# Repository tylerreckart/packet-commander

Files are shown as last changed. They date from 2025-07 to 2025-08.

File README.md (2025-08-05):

# Packet Commander
Complete 8-button WiFi IoT controller with hardware designs, firmware, and desktop configurator. Advanced configuration management, power optimization, and multi-protocol capabilities.

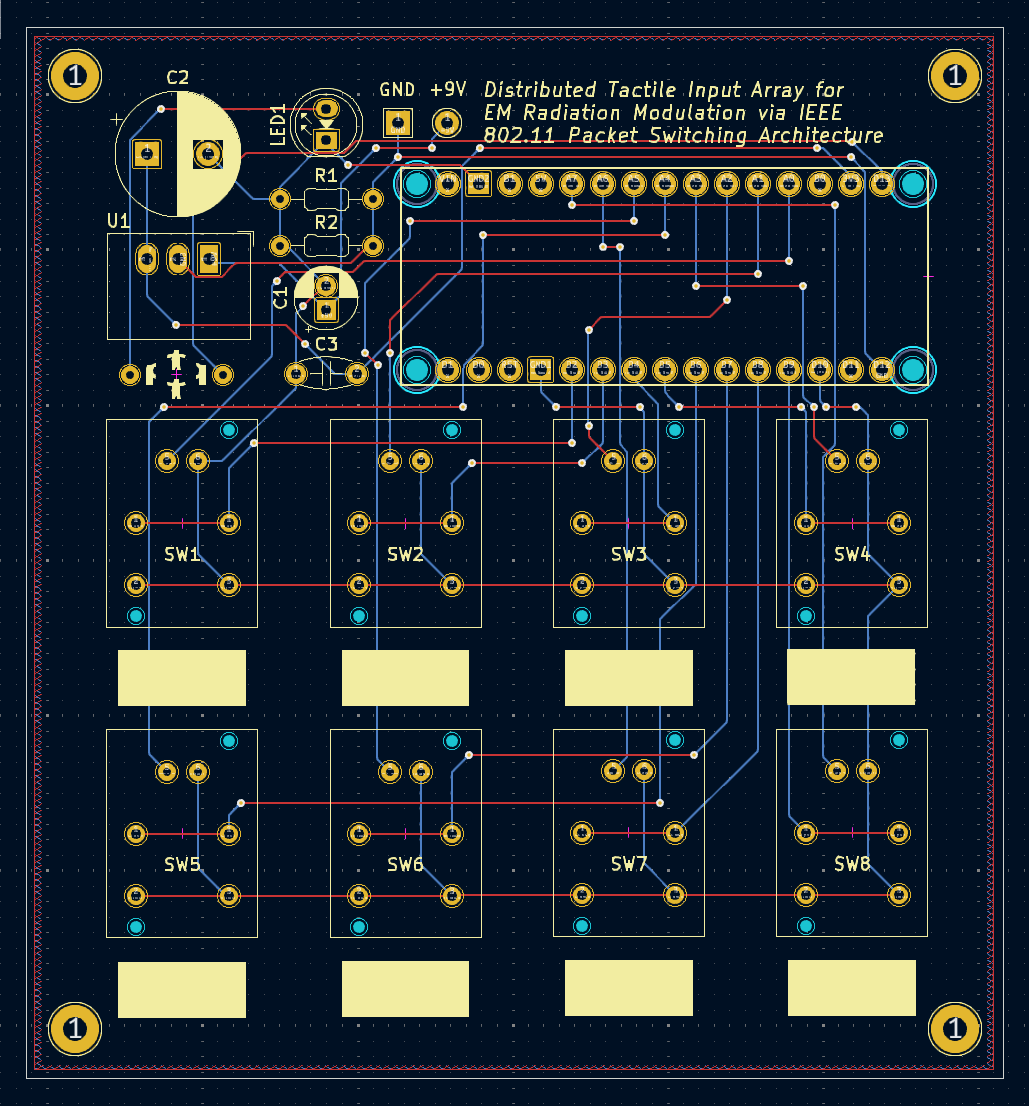
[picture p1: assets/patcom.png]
PATCOM


## Overview

Packet Commander is a complete IoT development platform featuring 8 programmable buttons with LED feedback, comprehensive WiFi connectivity, and intelligent power management. Includes hardware schematics, ESP32 firmware, and cross-platform Electron configurator for smart home automation, network testing, and custom IoT applications.

### Key Features
- **8 Programmable Buttons**: Directly supports HTTP and Webhook actions.
- **Smart Power Management**: Includes battery monitoring and optimized CPU frequency for power efficiency.
- **Desktop App**: Full-featured Electron configurator with device management.
- **Persistent Storage**: Configuration saved to flash memory on the device.
- **Multi-Protocol Support**: Firmware directly supports HTTP/HTTPS and Webhook.
- **Network Discovery**: Automatic device detection and configuration synchronization via the desktop application.

### Hardware Specs
- **MCU**: Arduino Nano ESP32 (Dual-core, 240MHz).
- **Inputs**: 8× illuminated tactile buttons (PB86).
- **Power**: 9V battery → 3.3V regulated (6-8 hour runtime).
- **Network**: 2.4GHz WiFi 802.11b/g/n.
- **Current**: 80-240mA.
- **Storage**: 4MB Flash, EEPROM for configuration.
- **Battery Monitor**: Real-time voltage sensing with low-battery alerts.

## Developer Quick Start

### For Configurator Development
```bash
# Install dependencies and run configurator
npm install
npm run build
npm run dev
```

### For Hardware Development
- Flash `firmware/patcom.cpp` to Arduino Nano ESP32
- Use configurator to connect and test device
- See [Circuit Assembly](#circuit-assembly) for complete build guide

### Prerequisites
- Node.js 18+ (for configurator)
- Arduino IDE 2.0+ (for firmware)
- KiCad (for hardware modifications)

## Quick Start

### 1. Hardware Setup
- Flash the firmware to your Arduino Nano ESP32.
- Connect 9V battery to power input.
- Power LED will indicate system status.

### 2. First Boot Configuration
1. Power on device - it will create "PATCOM-Config" WiFi hotspot.
2. Connect to hotspot (password: `patcom123`).
3. Open browser to `192.168.4.1`.
4. Configure your WiFi network and device settings.
5. Device will restart and connect to your network.

### 3. Desktop Configuration App

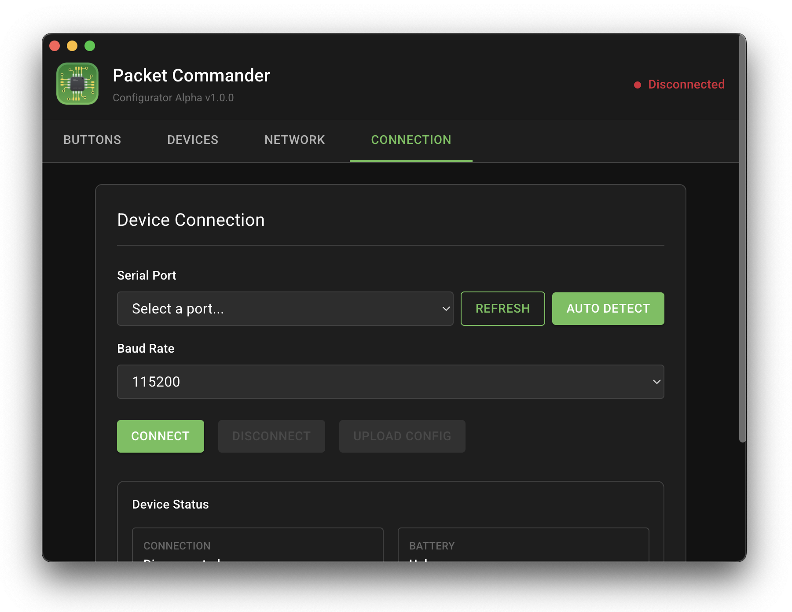
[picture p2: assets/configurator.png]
PATCOM Configurator


#### Development Commands
```bash
# Install dependencies
npm install

# Build all TypeScript
npm run build

# Run in development mode (with debug output)
npm run dev

# Run in production mode
npm start

# Build for distribution
npm run dist

# Type checking and linting
npm run type-check
npm run lint
```

#### Configurator Features
- **Device Auto-Detection**: USB serial and network discovery
- **Real-time Configuration**: Live button testing and LED control
- **Bulk Operations**: Configure multiple devices simultaneously
- **Configuration Backup**: Save/load device configurations as JSON
- **Debug Console**: Monitor device communication and troubleshoot issues

### 4. Device Discovery & Configuration
- Click "Discover Devices" to find controllers on your network
- Configure button actions: HTTP requests, webhooks.
- Upload configuration to device
- Test buttons and monitor activity

## Firmware Installation

### Arduino IDE Setup
- Download [Arduino IDE 2.0+](https://www.arduino.cc/en/software)
- Add ESP32 board URL in Preferences:
  ```
  https://espressif.github.io/arduino-esp32/package_esp32_index.json
  ```
- Install "Arduino ESP32 Boards" via Board Manager
- Install required libraries: ArduinoJson, AsyncUDP, ESPmDNS

### Firmware Upload
- Connect Arduino via USB-C
- Select: **Tools → Board → Arduino Nano ESP32**
- Select your port
- Open `firmware/patcom.cpp`
- Click Upload

## Configuration Management

### Button Action Types
- **HTTP/HTTPS**: Send GET/POST/PUT requests with custom headers and body
- **Webhook**: Secure webhook calls with device context and secrets
- **None**: Disable button (LED-only feedback)

### Device Settings
- **Network**: WiFi credentials, static IP configuration
- **Discovery**: Device name, auto-discovery, config sync settings
- **API Keys**: Secure storage for service credentials

### Configuration Storage
- Settings persisted to ESP32 flash memory
- Automatic backup during low battery
- Configuration hash verification
- Remote sync with desktop app

## Development & Debugging

### Device Communication
The configurator communicates with devices via:
- **USB Serial**: Direct connection for development (115200 baud)
- **Network Discovery**: UDP broadcast for deployed devices
- **HTTP API**: RESTful configuration on device port 80

### Debugging Tips
- Enable debug mode: `npm run dev` shows detailed console output
- Serial monitor: Built-in serial console for direct device communication
- Network scanner: "Discover Devices" shows all responsive controllers
- Configuration validation: Real-time validation with error highlighting

### File Structure
```
src/
├── main.ts              # Electron main process
├── preload.ts           # Secure IPC bridge  
├── renderer/            # UI components
├── services/            # Device communication
└── types/               # TypeScript definitions

firmware/
└── patcom.cpp           # ESP32 firmware

hardware/
└── *.kicad_*           # PCB design files
```

## Serial Commands (115200 baud)
- `STATUS` - Device information and battery status
- `CONFIG` - Display current configuration as JSON
- `SET_CONFIG:<json>` - Upload new configuration
- `TEST:<n>` - Test button n (0-7)
- `WIFI` - WiFi connection status
- `BATTERY` - Current battery voltage
- `HELP` - List all available commands

## Pin Connections

| Function | Pin | | Function | Pin |
|---|-----|-|---|-----|
| Button 0-7 | D2-D9 | | LED 0-7 | A0-A7 |
| Battery Monitor | A8 | | Status LED | D13 |
| Power In | 3V3 | | Ground | GND |
| USB Serial | USB-C | | Programming | BOOT + RESET |

## Circuit Assembly

### Parts List
- Packet Commander PCB
- Arduino Nano ESP32
- 8× PB86 switches
- RECOM R-78E3.3-1.0 regulator
- Capacitors: 100µF, 470µF, 10µF
- Resistors: 100kΩ, 33kΩ, 1kΩ
- 9V battery connector
- Terminal blocks

### Wiring
1. Battery → Regulator → Arduino 3V3 pin
2. Each button: terminal → Arduino pin, LED+ → analog pin
3. All grounds connected together
4. Battery monitor: voltage divider to D12

## Example Use Cases

### Smart Home Control
```json
{
  "action": "http",
  "config": {
    "url": "http://homeassistant.local:8123/api/services/light/toggle",
    "method": "POST",
    "headers": {"Authorization": "Bearer YOUR_TOKEN"},
    "body": "{\"entity_id\": \"light.living_room\"}"
  }
}
```

### Custom Webhook
```json
{
  "action": "webhook",
  "config": {
    "url": "https://api.example.com/webhook",
    "secret": "your-webhook-secret"
  }
}
```

## Troubleshooting

### Hardware Issues
| Issue | Solution |
|---|---|
| Upload fails | Hold RESET button during upload. Short GPIO0 to GND to reset the boot state. |
| No WiFi connection | Check 2.4GHz network, verify credentials |
| Short battery life | Normal: 6-8 hours, enable power saving |
| LEDs dim/flickering | Low battery or loose connections |
| Configuration not saving | Check flash memory, try factory reset |

### Configurator Issues  
| Issue | Solution |
|---|---|
| **Configurator won't start** | Run `npm run clean && npm install && npm run build` |
| **Device not detected** | Check USB drivers, try different cable, verify 115200 baud |
| **Network discovery fails** | Disable firewall, ensure same subnet, check UDP port 12345 |
| **Configuration upload fails** | Verify device connection, check JSON syntax, try smaller config |
| **Build errors** | Update Node.js to 18+, clear node_modules, reinstall |
| **TypeScript errors** | Run `npm run type-check` for detailed diagnostics |

## License

MIT License - Open source hardware and software.

## Contributing

Packet Commander is open source hardware and software. Contributions welcome for hardware, firmware, or configurator!

### Development Areas
- **Hardware**: PCB improvements, new form factors (`/hardware`)
- **Firmware**: ESP32 code, new protocols (`/firmware`) 
- **Configurator**: Electron app features (`/src`)

### Process
1. Fork the repository
2. Create a feature branch
3. Test with hardware if possible
4. Submit a pull request with detailed description

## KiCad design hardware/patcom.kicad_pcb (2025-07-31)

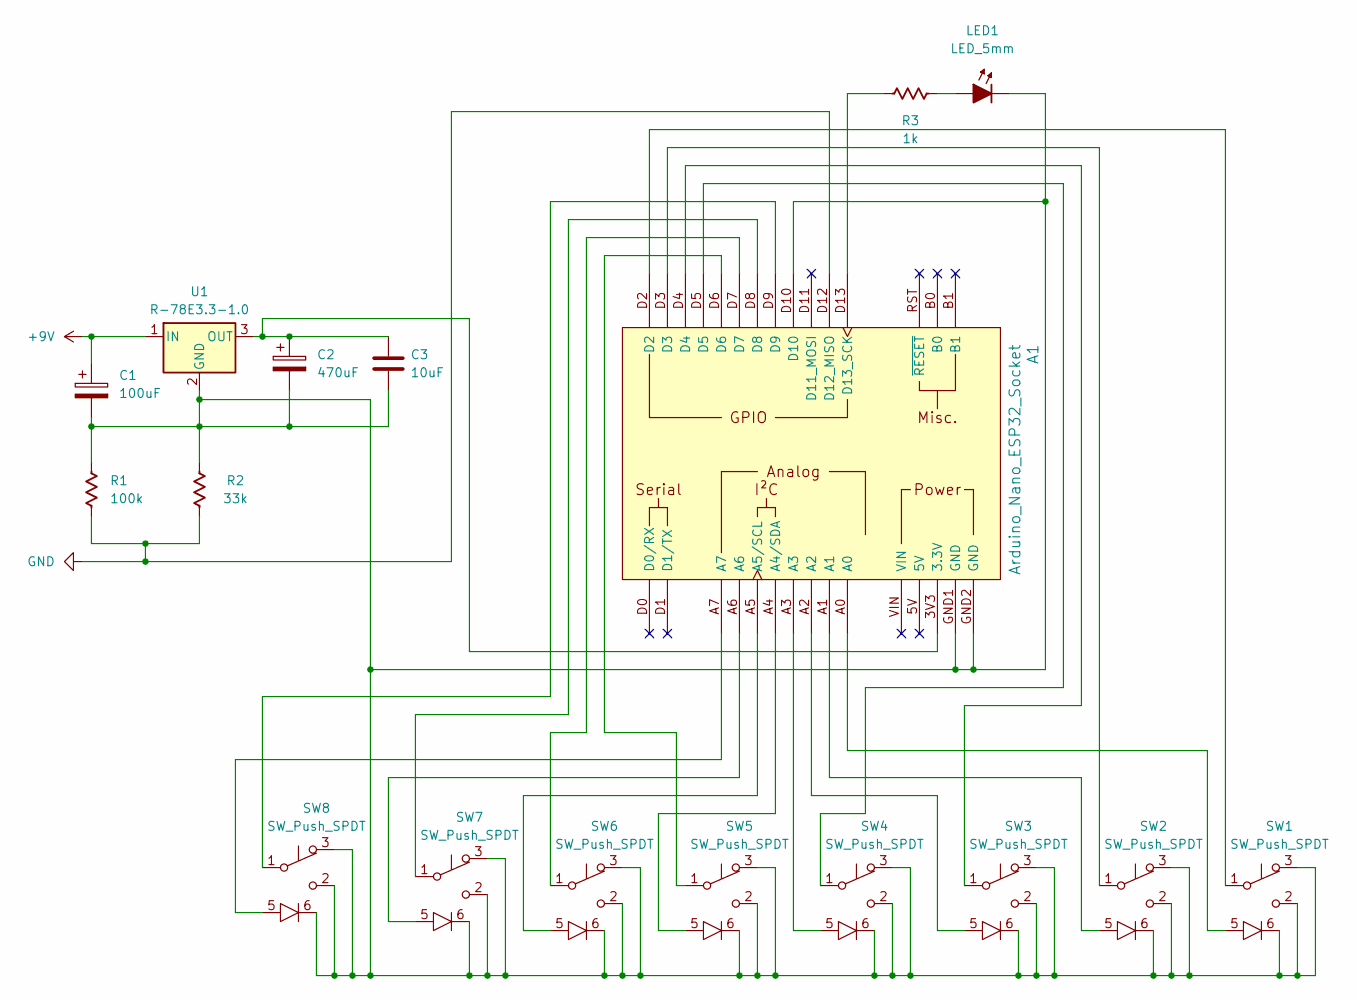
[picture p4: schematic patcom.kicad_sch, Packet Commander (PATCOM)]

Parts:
A1: Arduino_Nano_ESP32_Socket
C1: 100uF; CP_Radial_D5.0mm_P2.00mm
C2: 470uF; CP_Radial_D10.0mm_P5.00mm
C3: 10uF; C_Disc_D5.0mm_W2.5mm_P5.00mm
LED1: LED_5mm; LED_D5.0mm
R1: 100k; R_Axial_DIN0207_L6.3mm_D2.5mm_P10.16mm_Horizontal
R2: 33k; R_Axial_DIN0207_L6.3mm_D2.5mm_P10.16mm_Horizontal
R3: 1k; R_Axial_DIN0207_L6.3mm_D2.5mm_P10.16mm_Horizontal
SW1, SW2, SW3, SW4, SW5, SW6, SW7, SW8: SW_Push_SPDT; PB_86_A1
U1: R-78E3.3-1.0; Converter_DCDC_RECOM_R-78E-0.5_THT

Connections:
+9V: C1.1, U1.1 (IN); also elsewhere on the board
unnamed: A1.3V3 (3.3V), C2.1, C3.2, U1.3 (OUT)
unnamed: A1.A4 (A4/SDA), SW5.5 (LED+)
unnamed: A1.A5 (A5/SCL), SW6.5 (LED+)
unnamed: A1.D13 (D13_SCK), R3.2
unnamed: LED1.2 (A), R3.1
unnamed: A1.D2, SW1.1 (B)
unnamed: A1.A0, SW1.5 (LED+)
unnamed: A1.D3, SW2.1 (B)
unnamed: A1.A1, SW2.5 (LED+)
unnamed: A1.D4, SW3.1 (B)
unnamed: A1.A2, SW3.5 (LED+)
unnamed: A1.D5, SW4.1 (B)
unnamed: A1.A3, SW4.5 (LED+)
unnamed: A1.D6, SW5.1 (B)
unnamed: A1.D7, SW6.1 (B)
unnamed: A1.D8, SW7.1 (B)
unnamed: A1.A6, SW7.5 (LED+)
unnamed: A1.D9, SW8.1 (B)
unnamed: A1.A7, SW8.5 (LED+)

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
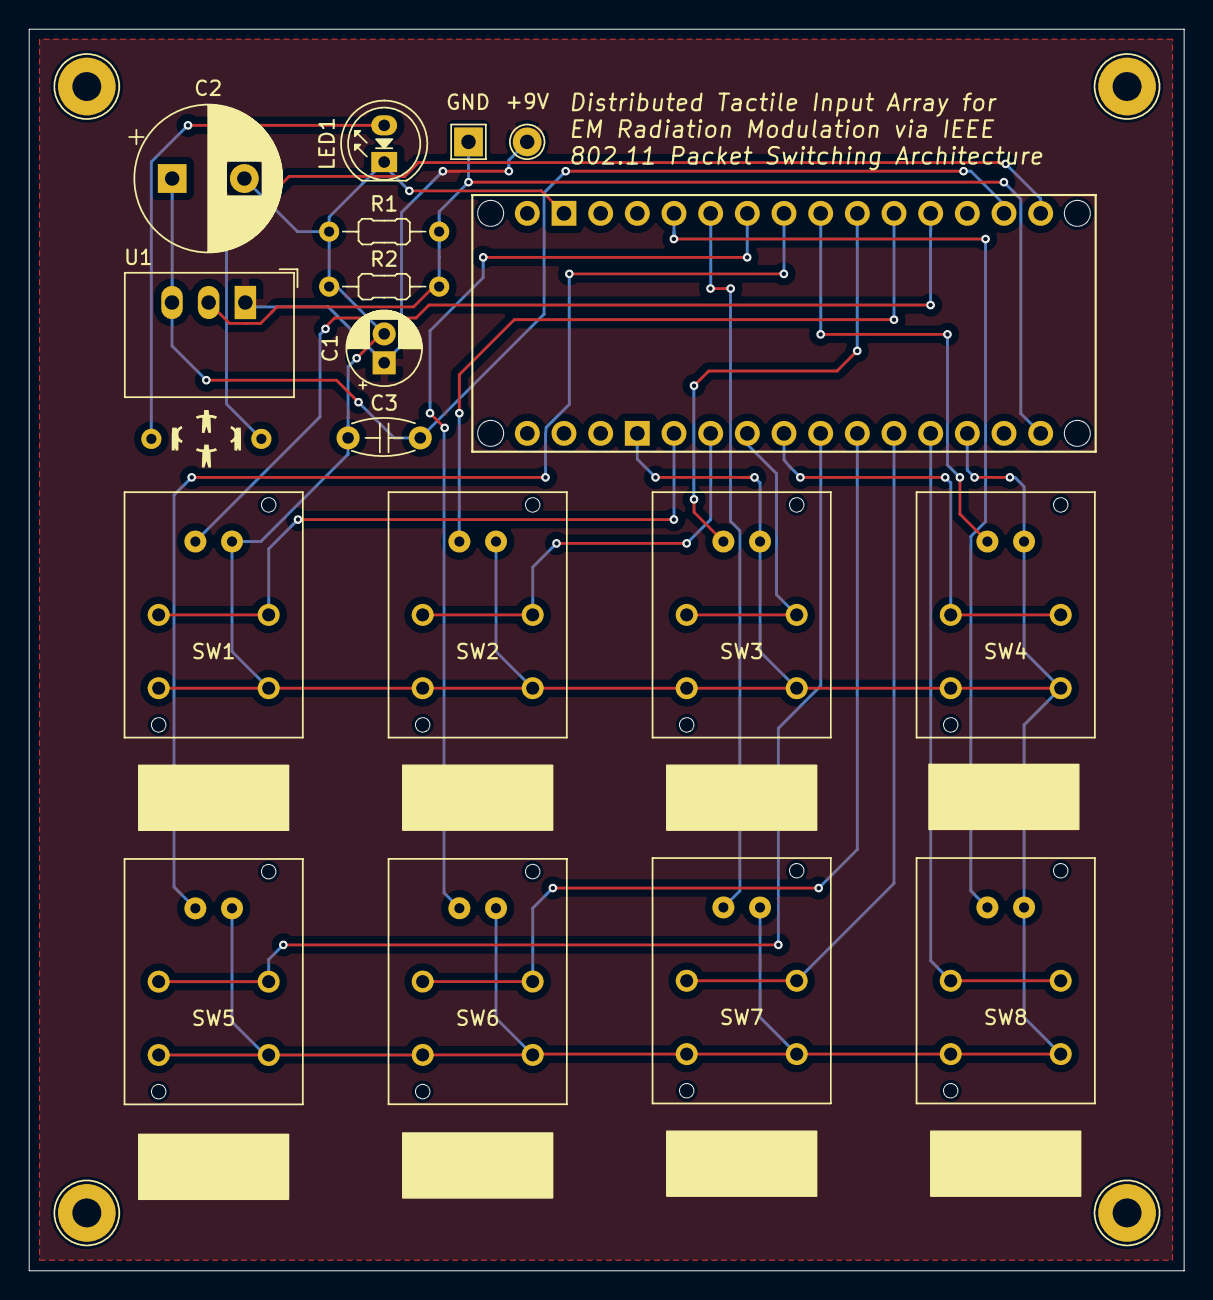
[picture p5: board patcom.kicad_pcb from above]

Board: 2 copper layers, 80.0 x 86.0 mm, 19 parts (0 on the bottom side), 22 nets.

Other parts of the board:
+9V: TestPoint_THTPad_D2.0mm_Drill1.0mm
GND: TestPoint_THTPad_2.0x2.0mm_Drill1.0mm

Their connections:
+9V: +9V.1; also elsewhere on the board

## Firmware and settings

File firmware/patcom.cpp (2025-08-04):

/*
 * Packet Commander - Universal Programmable Button Matrix Controller
 */
#include <WiFi.h>
#include <HTTPClient.h>
#include <ArduinoJson.h>
#include <Preferences.h>
#include <WebServer.h>

// Configuration constants
const char* DEVICE_NAME = "PATCOM";
const char* VERSION = "2.1.0";
const int CONFIG_SIZE = 8192;
// Heartbeat removed for simplification
const unsigned long BUTTON_DEBOUNCE = 50;   // Reduced for better responsiveness
const unsigned long BUTTON_HOLD_TIME = 100; // Minimum hold time for reliable detection
const unsigned long STATUS_LED_BLINK = 500;

// Pin assignments
const int buttonPins[8] = {2, 3, 4, 5, 6, 7, 8, 9};
const int ledPins[8] = {A0, A1, A2, A3, A4, A5, A6, A7};
const int BATTERY_PIN = 17;
const int STATUS_LED_PIN = 13;

// Action types
enum ActionType {
  ACTION_NONE = 0,
  ACTION_HTTP = 1,
  ACTION_WEBHOOK = 2
};

// Device types for multi-device support
enum DeviceType {
  DEVICE_TYPE_BUTTON_MATRIX = 0,
  DEVICE_TYPE_OUTLET_CONTROLLER = 1,
  DEVICE_TYPE_CUSTOM = 2
};

// Button configuration structure
struct ButtonConfig {
  char name[32];
  ActionType action;
  char actionData[256];  // JSON string for action parameters
  bool enabled;
};

// Network configuration structure
struct NetworkConfig {
  char ssid[64];
  char password[64];
  bool staticIP;
  char ip[16];
  char subnet[16];
  char gateway[16];
  char dns[16];
};

// Device configuration structure
struct DeviceConfig {
  char deviceName[32];
  char deviceId[16];
  DeviceType deviceType;
  int brightness;
  bool discoverable;
  char firmwareVersion[16];
  bool autoSync;
  char configServerUrl[128];
};

// API Keys configuration structure (universal key-value storage)
struct ApiKeyEntry {
  char name[32];
  char value[128];
  bool active;
};

const int MAX_API_KEYS = 16;

// Global variables
ButtonConfig buttonConfigs[8];
NetworkConfig networkConfig;
DeviceConfig deviceConfig;
ApiKeyEntry apiKeys[MAX_API_KEYS];
Preferences preferences;
WebServer server(80);

// State tracking
bool buttonStates[8] = {true, true, true, true, true, true, true, true};  // Start as released (HIGH)
bool buttonPressed[8] = {false, false, false, false, false, false, false, false}; // Track if button is currently pressed
unsigned long buttonPressStart[8] = {0}; // When button press started
bool ledStates[8] = {false};
unsigned long lastButtonPress[8] = {0};
unsigned long lastStatusBlink = 0;
bool statusLedState = false;
float batteryVoltage = 3.3;  // 3.3V power supply
bool wifiConnected = false;
bool configMode = false;
bool pinsStabilized = false;  // Flag to prevent early button detection

// Power monitoring state (sleep management removed)
bool criticalBattery = false;  // Keep name for compatibility but it's really critical power
int bootCount = 0;  // Removed RTC_DATA_ATTR since no sleep

// Status LED states
enum StatusLedMode {
  STATUS_OFF = 0,
  STATUS_CONNECTING,
  STATUS_ACTIVE,
  STATUS_LOW_POWER,
  STATUS_ERROR
};
StatusLedMode currentStatusMode = STATUS_OFF;

// Forward declarations
void setupPins();
void loadConfiguration();
void saveConfiguration();
void connectWiFi();
void setupWebServer();
void handleButtonPress(int buttonIndex);
void executeAction(int buttonIndex);
void executeHttpAction(int buttonIndex, const char* actionData);
void executeWebhookAction(int buttonIndex, const char* actionData);
void updateLEDs();
void handleSerialCommands();
void processSerialCommand(String command);
void sendJsonResponse(const char* type, const char* message, bool success = true);
void sendDeviceInfo();
void handleConfigUpload();
void handleConfigUpload(String configJson);
void validateConfiguration();
bool isValidIP(const char* ip);
bool isValidUrl(const char* url);
void updateStatusLED();
void setStatusLED(StatusLedMode mode);

void setup() {
  Serial.begin(115200);
  delay(100);
  
  // Increment boot count for debugging
  ++bootCount;
  
  Serial.println("\n=== PATCOM CONFIGURABLE v" + String(VERSION) + " ===");
  Serial.println("Boot #" + String(bootCount));
  Serial.println("Initializing...");
  
  // Setup hardware first to control status LED
  setupPins();
  
  // Simple status LED indication
  digitalWrite(STATUS_LED_PIN, HIGH);
  delay(200);
  digitalWrite(STATUS_LED_PIN, LOW);
  
  // Initialize all LEDs to OFF state
  for (int i = 0; i < 8; i++) {
    ledStates[i] = false;  // Set initial state
    analogWrite(ledPins[i], 0);    // Turn off
  }
  
  Serial.println("LEDs initialized");
  
  // Print pin mapping for debugging
  Serial.println("=== PIN MAPPING DEBUG ===");
  for (int i = 0; i < 8; i++) {
    Serial.println("Button " + String(i) + ": GPIO " + String(buttonPins[i]) + " -> LED pin " + String(ledPins[i]) + " (A" + String(i) + " = " + String(A0 + i) + ")");
  }
  Serial.println("========================");
  
  // Enable button checking after LED test is complete
  pinsStabilized = true;
  Serial.println("Button detection enabled");
  
  // Sleep wakeup detection removed
  Serial.println("Fresh start - sleep functions disabled");
  
  
  // Optimize CPU frequency for 3.3V operation and power efficiency
  setCpuFrequencyMhz(80);  // Reduced frequency for power savings
  Serial.println("Running at optimized frequency for power efficiency");
  
  // Load configuration from flash
  loadConfiguration();
  
  // Validate configuration
  validateConfiguration();
  
  // Power monitoring initialization
  Serial.println("Sleep functions disabled - device will stay awake");
  
  // Set status LED to connecting mode before WiFi
  setStatusLED(STATUS_CONNECTING);
  
  // Connect to WiFi
  connectWiFi();
  
  // Setup web server for configuration
  setupWebServer();
  
  
  // Set final status LED state
  if (wifiConnected) {
    setStatusLED(STATUS_ACTIVE);
  } else {
    setStatusLED(STATUS_ERROR);
  }
  
  Serial.println("Setup complete!");
  Serial.println("");
  Serial.println("");
  Serial.println("Commands: CONFIG, STATUS, WIFI, POWER, BATTERY, HELP, RESET_WIFI");
  if (configMode) {
    Serial.println("*** DEVICE IN CONFIG MODE ***");
    Serial.println("*** Connect to WiFi: PATCOM-Config ***");
    Serial.println("*** Password: patcom123 ***");
    Serial.println("*** Open browser to: 192.168.4.1 ***");
  }
  sendDeviceInfo();
}

void loop() {
  // Handle web server requests
  server.handleClient();
  
  // Check button presses (only after pins are stabilized)
  if (pinsStabilized) {
    for (int i = 0; i < 8; i++) {
      bool currentState = digitalRead(buttonPins[i]);
      unsigned long currentTime = millis();
      
      // Button pressed: transition from HIGH to LOW (with pullup)
      if (buttonStates[i] == true && currentState == false) {
        // Start tracking the press
        if (!buttonPressed[i]) {
          buttonPressed[i] = true;
          buttonPressStart[i] = currentTime;
        }
      }
      // Button released: transition from LOW to HIGH  
      else if (buttonStates[i] == false && currentState == true) {
        buttonStates[i] = true;  // Update state
        
        // If we were tracking a press, check if it was valid
        if (buttonPressed[i]) {
          unsigned long pressDuration = currentTime - buttonPressStart[i];
          if (pressDuration >= BUTTON_HOLD_TIME && 
              (currentTime - lastButtonPress[i]) > BUTTON_DEBOUNCE) {
            lastButtonPress[i] = currentTime;
            handleButtonPress(i);
          }
          buttonPressed[i] = false;
        }
      }
      
      // Update button state based on current reading
      if (currentState == false && buttonPressed[i]) {
        // Check if we've held the button long enough
        unsigned long pressDuration = currentTime - buttonPressStart[i];
        if (pressDuration >= BUTTON_HOLD_TIME && buttonStates[i] == true &&
            (currentTime - lastButtonPress[i]) > BUTTON_DEBOUNCE) {
          buttonStates[i] = false;  // Update state
          lastButtonPress[i] = currentTime;
          handleButtonPress(i);
          buttonPressed[i] = false; // Prevent multiple triggers
        }
      }
      
      // Reset press tracking if button has been held too long (prevent stuck buttons)
      if (buttonPressed[i] && (currentTime - buttonPressStart[i]) > 2000) {
        buttonPressed[i] = false;
      }
    }
  }
  
  // Update status LED
  updateStatusLED();
  
  // Handle serial commands
  handleSerialCommands();
  
  
  // Update LEDs
  updateLEDs();
  
  // Reduced delay for better button responsiveness
  delay(10);  // Faster polling for reliable button detection
}

void setupPins() {
  Serial.println("Setting up pins...");
  
  // Set global PWM frequency and resolution for ESP32
  analogWriteFrequency(5000);  // 5kHz PWM frequency
  analogWriteResolution(8);    // 8-bit resolution (0-255)
  
  // Configure LED pins first (safe state)  
  for (int i = 0; i < 8; i++) {
    pinMode(ledPins[i], OUTPUT);
    analogWrite(ledPins[i], 0);  // Set to off initially
    Serial.println("LED " + String(i) + " pin " + String(ledPins[i]) + " configured");
  }
  
  // Configure other pins
  pinMode(BATTERY_PIN, INPUT);
  pinMode(STATUS_LED_PIN, OUTPUT);
  digitalWrite(STATUS_LED_PIN, LOW);
  
  // Wait for pins to stabilize
  delay(500);
  
  // Configure buttons with internal pullup - LAST
  for (int i = 0; i < 8; i++) {
    pinMode(buttonPins[i], INPUT_PULLUP);
    // Read initial state to stabilize
    digitalRead(buttonPins[i]);
    buttonStates[i] = true;  // Assume released (HIGH with pullup)
    lastButtonPress[i] = millis();  // Initialize timing
    Serial.println("Button " + String(i) + " pin " + String(buttonPins[i]) + " configured, initial state: " + String(digitalRead(buttonPins[i])));
  }
  
  Serial.println("Pin setup complete - waiting for stabilization...");
  delay(1000);  // Give pins time to stabilize
}

void loadConfiguration() {
  preferences.begin("patcom", true);
  
  // Load device config
  strcpy(deviceConfig.deviceName, preferences.getString("deviceName", "PATCOM").c_str());
  strcpy(deviceConfig.deviceId, preferences.getString("deviceId", "PATCOM-" + String(ESP.getEfuseMac(), HEX)).c_str());
  deviceConfig.deviceType = (DeviceType)preferences.getInt("deviceType", DEVICE_TYPE_BUTTON_MATRIX);
  deviceConfig.brightness = preferences.getInt("brightness", 255);
  deviceConfig.discoverable = preferences.getBool("discoverable", true);
  // heartbeatInterval removed
  strcpy(deviceConfig.firmwareVersion, VERSION);
  deviceConfig.autoSync = preferences.getBool("autoSync", false);
  strcpy(deviceConfig.configServerUrl, preferences.getString("configServer", "").c_str());
  
  // Load API keys
  int apiKeyCount = preferences.getInt("apiKeyCount", 0);
  for (int i = 0; i < MAX_API_KEYS; i++) {
    apiKeys[i].active = false;
    strcpy(apiKeys[i].name, "");
    strcpy(apiKeys[i].value, "");
  }
  
  for (int i = 0; i < apiKeyCount && i < MAX_API_KEYS; i++) {
    String prefix = "apiKey" + String(i) + "_";
    strcpy(apiKeys[i].name, preferences.getString((prefix + "name").c_str(), "").c_str());
    strcpy(apiKeys[i].value, preferences.getString((prefix + "value").c_str(), "").c_str());
    apiKeys[i].active = strlen(apiKeys[i].name) > 0;
  }
  
  
  // Load network config
  strcpy(networkConfig.ssid, preferences.getString("ssid", "").c_str());
  strcpy(networkConfig.password, preferences.getString("password", "").c_str());
  networkConfig.staticIP = preferences.getBool("staticIP", false);
  strcpy(networkConfig.ip, preferences.getString("ip", "").c_str());
  strcpy(networkConfig.subnet, preferences.getString("subnet", "").c_str());
  strcpy(networkConfig.gateway, preferences.getString("gateway", "").c_str());
  strcpy(networkConfig.dns, preferences.getString("dns", "8.8.8.8").c_str());
  
  // Load button configs
  for (int i = 0; i < 8; i++) {
    String prefix = "btn" + String(i) + "_";
    strcpy(buttonConfigs[i].name, preferences.getString((prefix + "name").c_str(), ("Button " + String(i)).c_str()).c_str());
    buttonConfigs[i].action = (ActionType)preferences.getInt((prefix + "action").c_str(), ACTION_NONE);
    strcpy(buttonConfigs[i].actionData, preferences.getString((prefix + "data").c_str(), "{}").c_str());
    buttonConfigs[i].enabled = preferences.getBool((prefix + "enabled").c_str(), true);
  }
  
  preferences.end();
  Serial.println("Configuration loaded from flash");
}

void saveConfiguration() {
  preferences.begin("patcom", false);
  
  // Save device config
  preferences.putString("deviceName", deviceConfig.deviceName);
  preferences.putString("deviceId", deviceConfig.deviceId);
  preferences.putInt("deviceType", deviceConfig.deviceType);
  preferences.putInt("brightness", deviceConfig.brightness);
  preferences.putBool("discoverable", deviceConfig.discoverable);
  // heartbeat setting removed
  preferences.putBool("autoSync", deviceConfig.autoSync);
  preferences.putString("configServer", deviceConfig.configServerUrl);
  
  // Save API keys
  int activeApiKeyCount = 0;
  for (int i = 0; i < MAX_API_KEYS; i++) {
    if (apiKeys[i].active) {
      String prefix = "apiKey" + String(activeApiKeyCount) + "_";
      preferences.putString((prefix + "name").c_str(), apiKeys[i].name);
      preferences.putString((prefix + "value").c_str(), apiKeys[i].value);
      activeApiKeyCount++;
    }
  }
  preferences.putInt("apiKeyCount", activeApiKeyCount);
  
  
  // Save network config
  preferences.putString("ssid", networkConfig.ssid);
  preferences.putString("password", networkConfig.password);
  preferences.putBool("staticIP", networkConfig.staticIP);
  preferences.putString("ip", networkConfig.ip);
  preferences.putString("subnet", networkConfig.subnet);
  preferences.putString("gateway", networkConfig.gateway);
  preferences.putString("dns", networkConfig.dns);
  
  // Save button configs
  for (int i = 0; i < 8; i++) {
    String prefix = "btn" + String(i) + "_";
    preferences.putString((prefix + "name").c_str(), buttonConfigs[i].name);
    preferences.putInt((prefix + "action").c_str(), buttonConfigs[i].action);
    preferences.putString((prefix + "data").c_str(), buttonConfigs[i].actionData);
    preferences.putBool((prefix + "enabled").c_str(), buttonConfigs[i].enabled);
  }
  
  preferences.end();
  Serial.println("Configuration saved to flash");
}

void connectWiFi() {
  Serial.println("=== WiFi Connection Debug ===");
  Serial.println("SSID length: " + String(strlen(networkConfig.ssid)));
  Serial.println("SSID: '" + String(networkConfig.ssid) + "'");
  
  if (strlen(networkConfig.ssid) == 0) {
    Serial.println("No WiFi credentials - entering config mode");
    configMode = true;
    setStatusLED(STATUS_ERROR);
    
    // Start AP mode immediately when no credentials
    WiFi.mode(WIFI_AP);
    bool apResult = WiFi.softAP("PATCOM-Config", "patcom123");
    Serial.println("AP creation result: " + String(apResult ? "SUCCESS" : "FAILED"));
    Serial.println("AP started: PATCOM-Config");
    Serial.println("AP IP: " + WiFi.softAPIP().toString());
    Serial.println("Connect to PATCOM-Config with password: patcom123");
    return;
  }
  
  Serial.print("Connecting to WiFi: " + String(networkConfig.ssid));
  
  // Configure static IP if enabled
  if (networkConfig.staticIP && strlen(networkConfig.ip) > 0) {
    IPAddress local_IP, gateway, subnet, dns;
    local_IP.fromString(networkConfig.ip);
    gateway.fromString(networkConfig.gateway);
    subnet.fromString(networkConfig.subnet);
    dns.fromString(networkConfig.dns);
    
    if (!WiFi.config(local_IP, gateway, subnet, dns)) {
      Serial.println("Static IP configuration failed");
    }
  }
  
  WiFi.begin(networkConfig.ssid, networkConfig.password);
  
  int attempts = 0;
  while (WiFi.status() != WL_CONNECTED && attempts < 20) {
    delay(1000);  // Longer delay to reduce power consumption
    Serial.print(".");
    attempts++;
  }
  
  if (WiFi.status() == WL_CONNECTED) {
    wifiConnected = true;
    Serial.println("\nWiFi connected!");
    Serial.println("IP address: " + WiFi.localIP().toString());
    
    // Status LED will be set to ACTIVE in setup()
  } else {
    wifiConnected = false;
    Serial.println("\nWiFi connection failed - entering config mode");
    configMode = true;
    setStatusLED(STATUS_ERROR);
    
    // Start AP mode for configuration
    WiFi.mode(WIFI_AP);
    delay(100);  // Give time for mode switch
    bool apResult = WiFi.softAP("PATCOM-Config", "patcom123");
    Serial.println("AP creation result: " + String(apResult ? "SUCCESS" : "FAILED"));
    Serial.println("AP started: PATCOM-Config");
    Serial.println("AP IP: " + WiFi.softAPIP().toString());
    Serial.println("Connect to PATCOM-Config with password: patcom123");
    
    // Print available networks for debugging
    Serial.println("Scanning for networks...");
    int n = WiFi.scanNetworks();
    if (n == 0) {
      Serial.println("No networks found");
    } else {
      Serial.println(String(n) + " networks found:");
      for (int i = 0; i < n; ++i) {
        Serial.println(String(i + 1) + ": " + WiFi.SSID(i) + " (" + WiFi.RSSI(i) + "dBm)");
      }
    }
  }
}

void setupWebServer() {
  // Serve configuration page
  server.on("/", HTTP_GET, []() {
    String html = "<!DOCTYPE html><html><head><title>PATCOM Config</title></head><body>";
    html += "<h1>PATCOM Configuration</h1>";
    html += "<p>Device: " + String(deviceConfig.deviceName) + "</p>";
    html += "<p>Version: " + String(VERSION) + "</p>";
    html += "<p>WiFi: " + String(wifiConnected ? "Connected" : "Disconnected") + "</p>";
    html += "<p>Power: " + String(batteryVoltage, 2) + "V</p>";
    html += "</body></html>";
    server.send(200, "text/html", html);
  });
  
  // API endpoint for configuration
  server.on("/api/config", HTTP_GET, []() {
    StaticJsonDocument<2048> doc;
    doc["device"]["name"] = deviceConfig.deviceName;
    doc["device"]["version"] = VERSION;
    doc["device"]["brightness"] = deviceConfig.brightness;
    doc["device"]["discoverable"] = deviceConfig.discoverable;
    
    doc["network"]["ssid"] = networkConfig.ssid;
    doc["network"]["staticIP"] = networkConfig.staticIP;
    doc["network"]["ip"] = networkConfig.ip;
    doc["network"]["subnet"] = networkConfig.subnet;
    doc["network"]["gateway"] = networkConfig.gateway;
    
    JsonArray buttons = doc.createNestedArray("buttons");
    for (int i = 0; i < 8; i++) {
      JsonObject btn = buttons.createNestedObject();
      btn["id"] = i;
      btn["name"] = buttonConfigs[i].name;
      btn["action"] = buttonConfigs[i].action;
      btn["enabled"] = buttonConfigs[i].enabled;
      
      // Parse action data JSON
      StaticJsonDocument<256> actionDoc;
      deserializeJson(actionDoc, buttonConfigs[i].actionData);
      btn["config"] = actionDoc;
    }
    
    String response;
    serializeJson(doc, response);
    server.send(200, "application/json", response);
  });
  
  // API endpoint for uploading configuration
  server.on("/api/config", HTTP_POST, []() {
    handleConfigUpload();
  });
  
  // API endpoint for button testing
  server.on("/api/test", HTTP_POST, []() {
    if (server.hasArg("button")) {
      int buttonIndex = server.arg("button").toInt();
      if (buttonIndex >= 0 && buttonIndex < 8) {
        handleButtonPress(buttonIndex);
        server.send(200, "application/json", "{\"status\":\"ok\",\"message\":\"Button " + String(buttonIndex) + " triggered\"}");
      } else {
        server.send(400, "application/json", "{\"status\":\"error\",\"message\":\"Invalid button index\"}");
      }
    } else {
      server.send(400, "application/json", "{\"status\":\"error\",\"message\":\"Missing button parameter\"}");
    }
  });
  
  server.begin();
  Serial.println("Web server started on port 80");
}

void handleButtonPress(int buttonIndex) {
  if (buttonIndex < 0 || buttonIndex >= 8) return;
  
  Serial.println("=== BUTTON " + String(buttonIndex) + " PRESSED ===");
  Serial.println("Button name: " + String(buttonConfigs[buttonIndex].name));
  Serial.println("Pin: " + String(buttonPins[buttonIndex]) + " -> LED: " + String(ledPins[buttonIndex]));
  
  // Toggle LED state for visual feedback
  ledStates[buttonIndex] = !ledStates[buttonIndex];
  
  // Debug output for buttons 5-7 LED state
  if (buttonIndex >= 5) {
    int brightness = map(deviceConfig.brightness, 0, 255, 0, 255);
    Serial.println("LED " + String(buttonIndex) + " pin " + String(ledPins[buttonIndex]) + " (A" + String(buttonIndex) + ") new state: " + String(ledStates[buttonIndex]) + " brightness: " + String(brightness));
    Serial.println("Pin value: " + String(ledPins[buttonIndex]) + " (expected A" + String(buttonIndex) + " = " + String(A0 + buttonIndex) + ")");
  }
  
  // Apply the state immediately
  updateLEDs();
  
  // Execute configured action
  if (buttonConfigs[buttonIndex].enabled) {
    executeAction(buttonIndex);
  }
  
  // Send button press notification
  StaticJsonDocument<128> doc;
  doc["type"] = "button_press";
  doc["button"] = buttonIndex;
  doc["name"] = buttonConfigs[buttonIndex].name;
  doc["timestamp"] = millis();
  
  String message;
  serializeJson(doc, message);
  Serial.println("EVENT:" + message);
  Serial.println("========================");
}

void executeAction(int buttonIndex) {
  ActionType action = buttonConfigs[buttonIndex].action;
  const char* actionData = buttonConfigs[buttonIndex].actionData;
  
  switch (action) {
    case ACTION_HTTP:
      executeHttpAction(buttonIndex, actionData);
      break;
    case ACTION_WEBHOOK:
      executeWebhookAction(buttonIndex, actionData);
      break;
    case ACTION_NONE:
    default:
      Serial.println("No action configured for button " + String(buttonIndex));
      break;
  }
}
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

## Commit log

2025-07-24 initialize repository
    [patcom.kicad_pcb, patcom.kicad_sch]
2025-07-25 update pcb
    [patcom.kicad_pcb]
2025-07-31 basic configurator
    [patcom.kicad_pcb, patcom.kicad_sch]
